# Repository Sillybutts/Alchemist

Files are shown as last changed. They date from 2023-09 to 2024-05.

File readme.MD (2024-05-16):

# Alchemist
Alchemist is the next step in the evolution of 3d printed pump action springers.

<details>
<summary>Changelog (click this text, it's a dropdown!)</summary>

- Changelog: 10-14-2023: Blaster release.
- Changelog: 3-7-2024: A bunch of updates. 
- - Updated the sear and the plunger rod to be more wear-resistant and smoother to prime. Both these parts can be installed in existing Alchemists, you just need to take off the stock and install the sear from behind the PTback. The new plunger rod and sear are marked with 'V2' on the side.
- - Updated the PTback and Skeggox PTback to have space to install the new style of sear from the front without stock disassembly in the future. 
- - Updated the Skeggox PTback to have more space for the head of the large top bolt, and more space for the screwdriver. 
- - Removed the optional secondary trigger spring. The slight benefit in trigger feel is not worth the catch issues it causes for some people. 
- - Thinned the walls on the built in supports for the picatinny rails. Used to be 1mm wide, now 0.5mm wide.
- - Tightened the picatinny keepers for the pump grip and the Skeggox stock (upon recommendation from OOD).
- - Lengthened the Skeggox picatinny rail a HAIR to fix a tolerance (upon recommendation from OOD).
- - Added two pins to the back of the Skeggox picatinny to reinforce it. The pins go into new holes in the Skeggox PTback. 
- - Extended the sear spring a little bit more via a new optional grip print.
- - Chamfered the front bottom edges of the grip panels to better clear the mag release. (same for the Lynx-grip version's grip panels). 
- - Tightened the ball detent hole by a hair. 
- - Tweaked the MagwellBack to have more mag release clearance.
- - Added a TOP marking to the top of the trigger.
- - Extended the part of the trigger that touches the sear by a little bit to remove some slop.

</details>

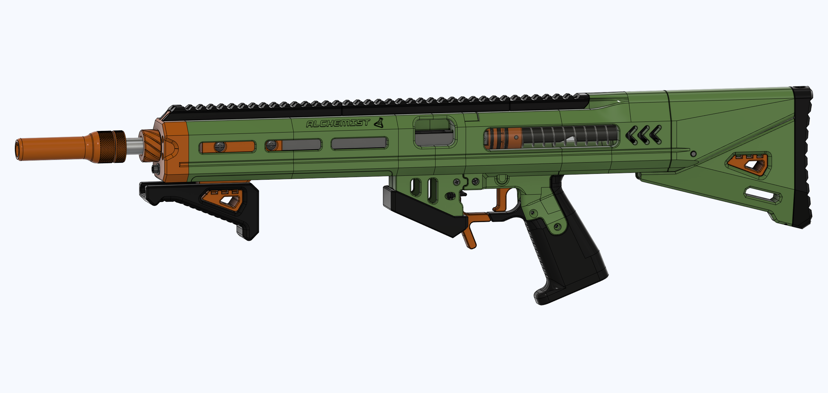
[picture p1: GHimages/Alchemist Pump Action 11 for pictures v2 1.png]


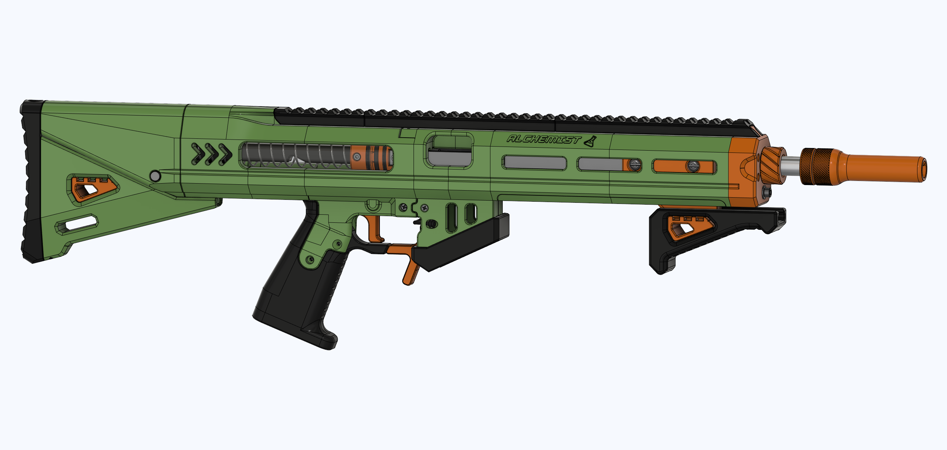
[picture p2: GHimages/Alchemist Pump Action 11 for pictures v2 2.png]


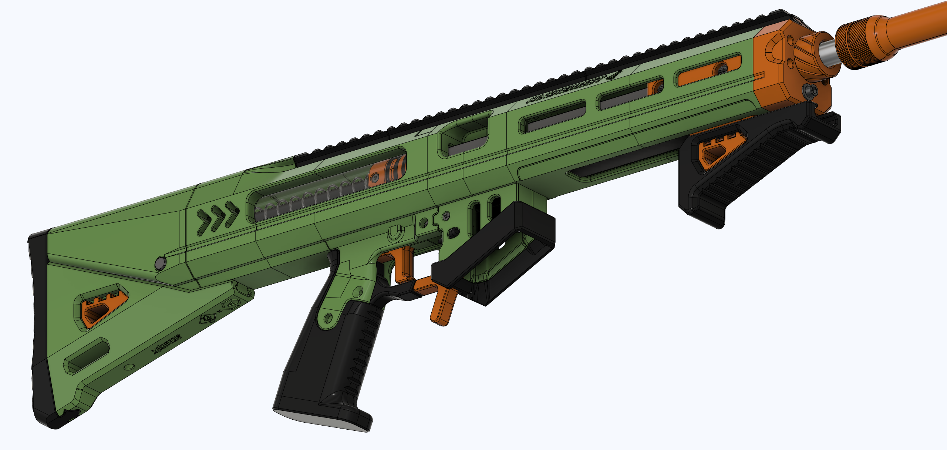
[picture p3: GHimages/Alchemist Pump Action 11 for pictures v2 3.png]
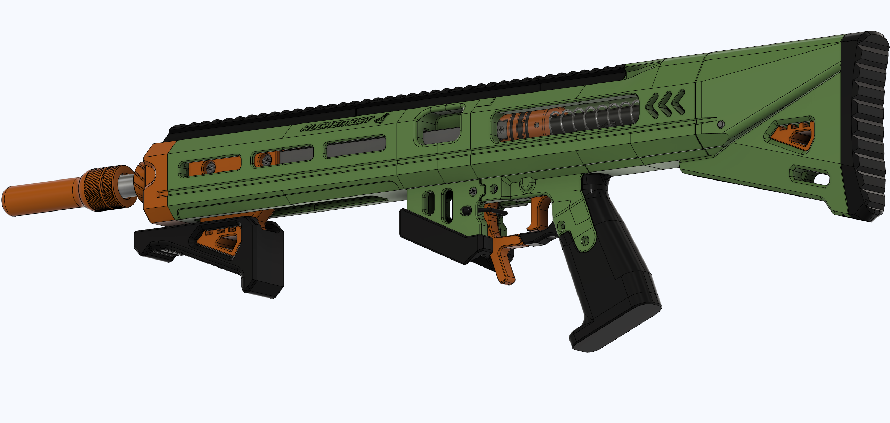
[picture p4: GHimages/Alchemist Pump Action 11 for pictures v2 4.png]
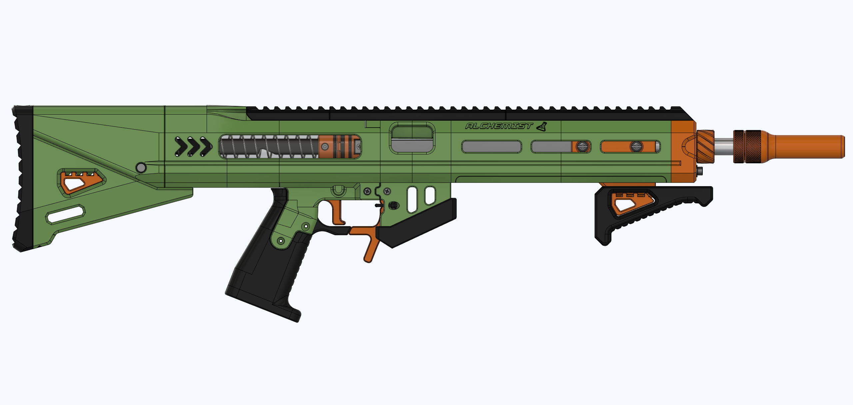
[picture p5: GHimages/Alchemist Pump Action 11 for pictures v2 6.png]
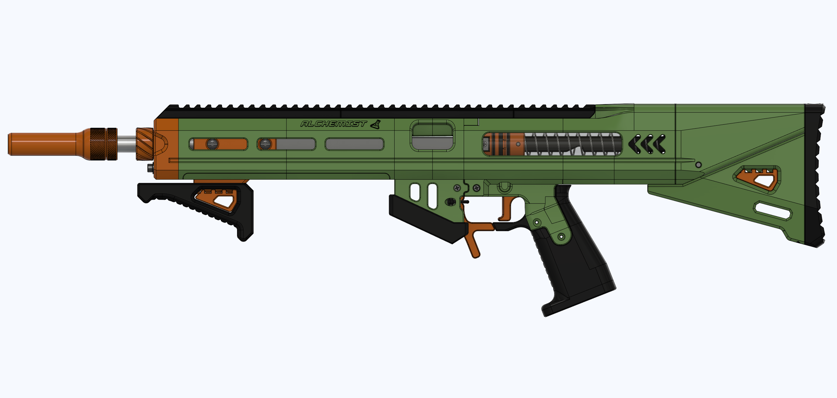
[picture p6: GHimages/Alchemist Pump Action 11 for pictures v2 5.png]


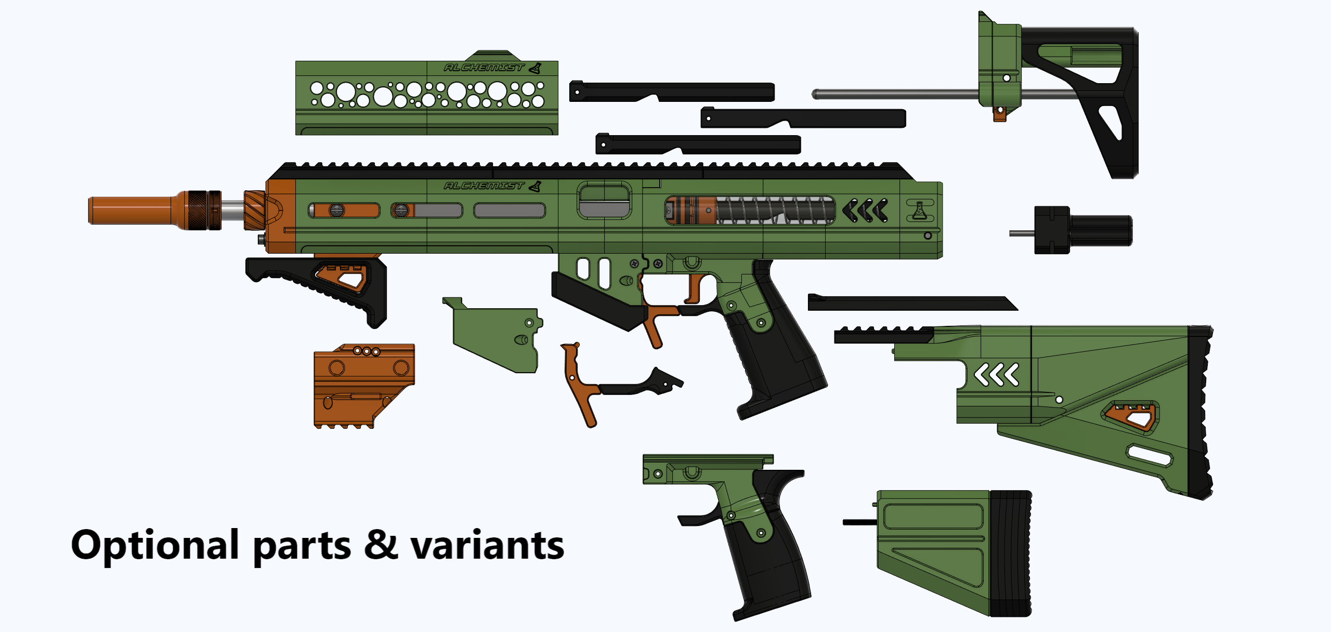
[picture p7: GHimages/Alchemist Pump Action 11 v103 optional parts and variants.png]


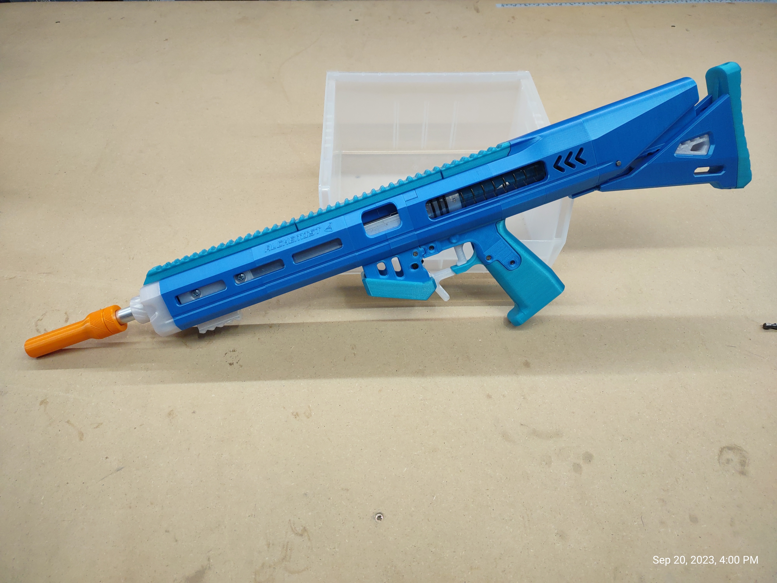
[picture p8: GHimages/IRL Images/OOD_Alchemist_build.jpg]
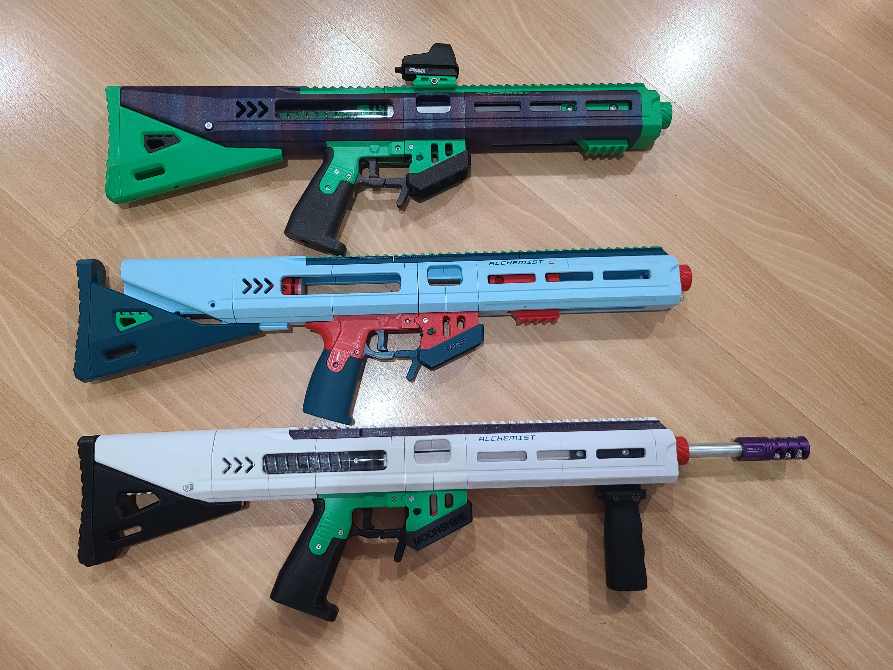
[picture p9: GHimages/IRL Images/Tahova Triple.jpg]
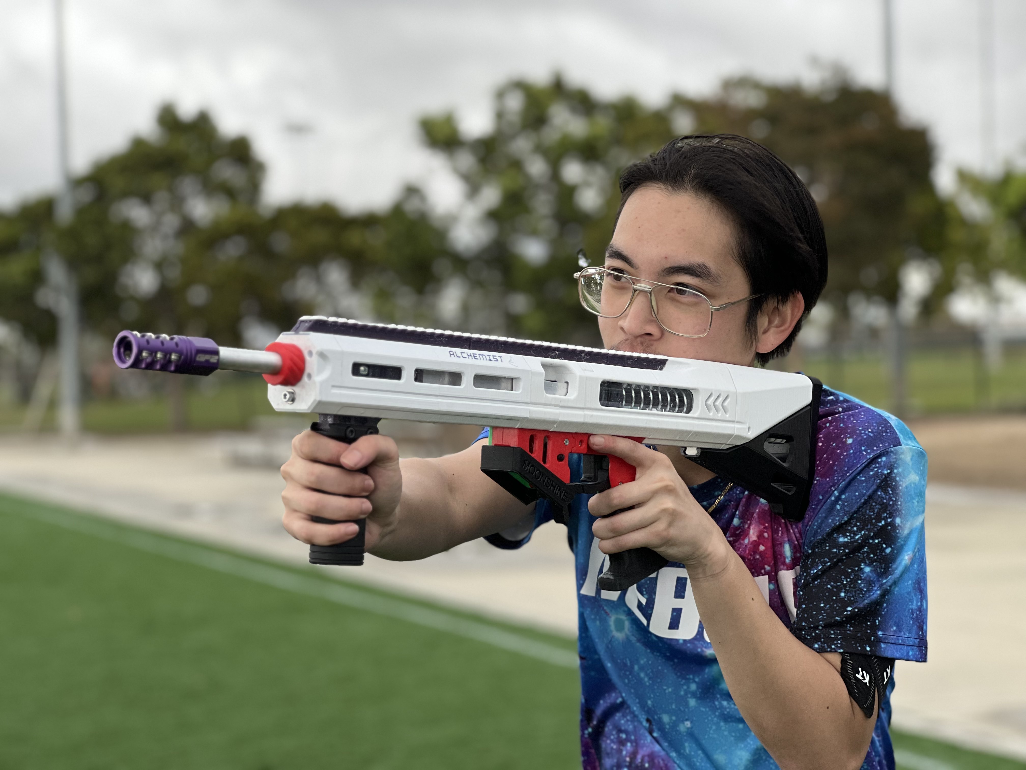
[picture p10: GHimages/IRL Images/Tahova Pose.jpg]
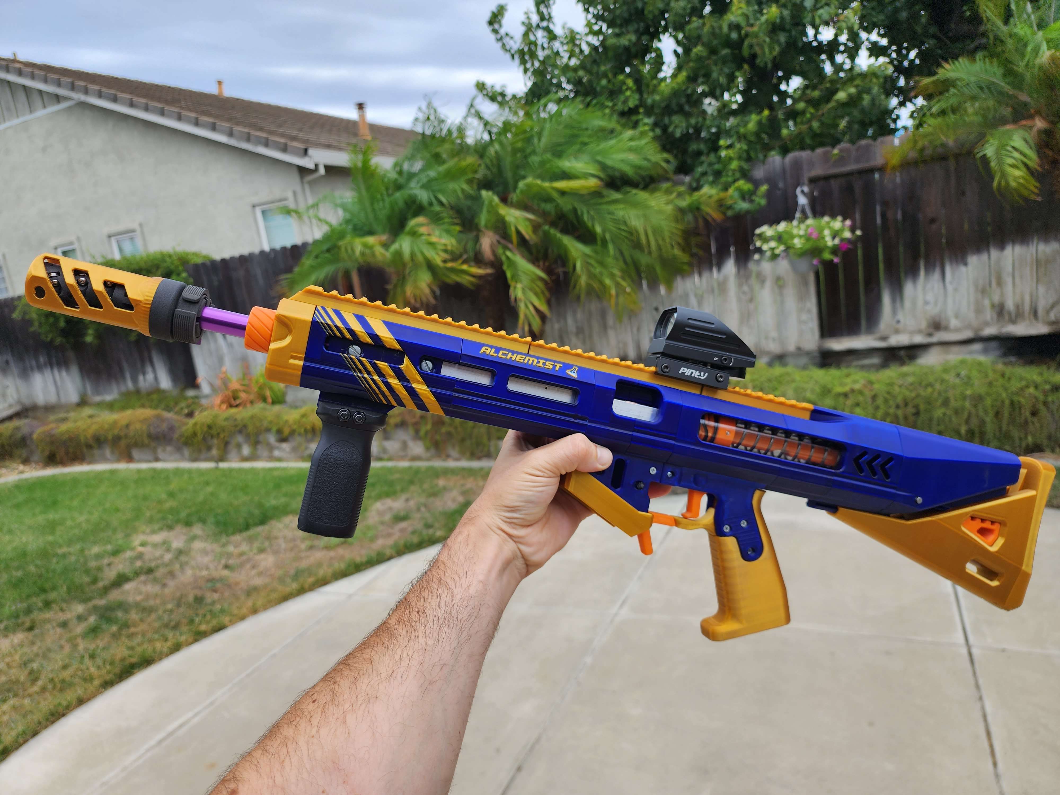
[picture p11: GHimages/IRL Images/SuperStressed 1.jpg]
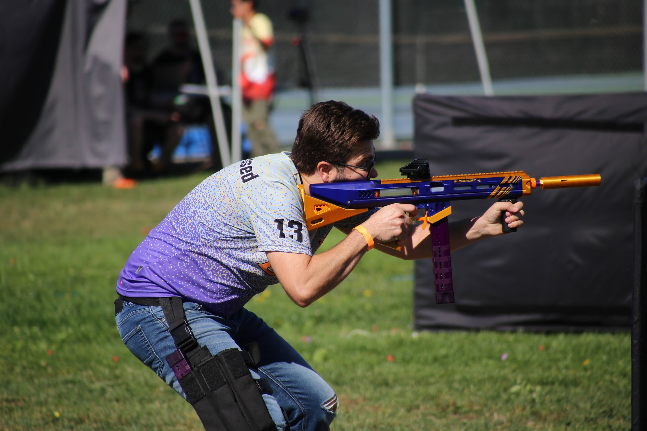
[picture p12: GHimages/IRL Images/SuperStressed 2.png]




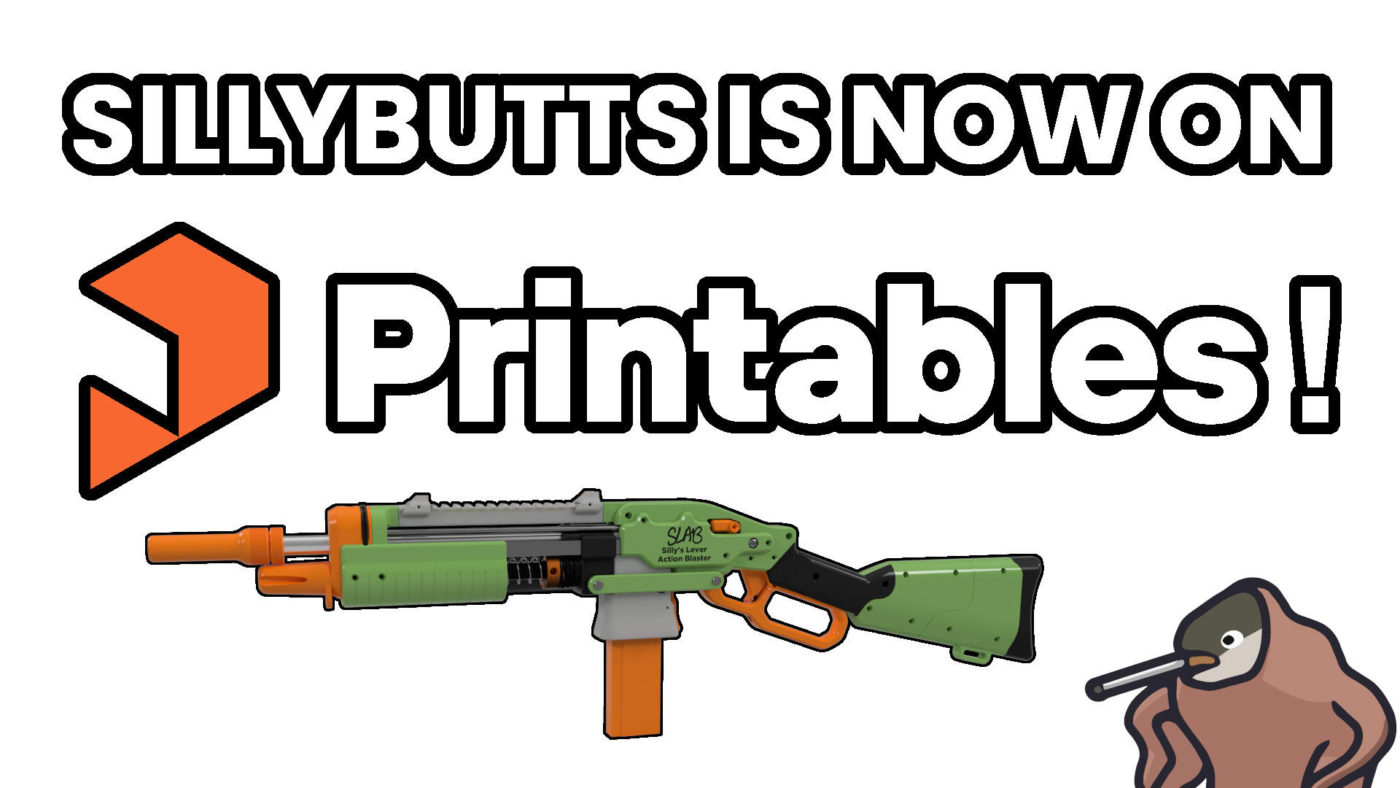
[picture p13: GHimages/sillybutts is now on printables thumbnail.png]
Printables Button


## I ALSO UPLOAD TO PRINTABLES https://www.printables.com/model/822837-alchemist-pump-action-blaster-nerf-homemade

## Description
Alchemist is the next step in the evolution of 3d printed pump action springers. Alchemist is built like a tank, has a butter smooth priming and firing feel, and is heavily customizable with alternative parts and upgrades. 

Firing Demo & Blaster Overview: https://www.youtube.com/watch?v=2bPMUlzL2F4

Pre-Release Compilation: https://youtu.be/aXrQAO-OECE

Assembly Video: https://youtu.be/UOdZIeP3myw

## "Why would I build this instead of XYZ?"

* It uses ball bearings on the priming grip, and the prime is VERY smooth.
* There is an (optional) ball detent that locks the priming grip in the forward position, so it doesn't flop around while running. Flopping is an issue experienced by most pump action springers (Talon Claw, SBL, Lynx, etc etc).
* One pin and one allen key screw to access the spring, plunger, and ram.
* The blaster is built on aluminum bars, like a Lynx. Very sturdy.
   * It also has a bar tensioner, which squeezes all the parts together like a Caliburnoid. Best of both worlds.
* Hair trigger, very quick and snappy.
* The barrel can be removed and replaced in 10 seconds, toolless.
   * If you don't care about doing barrel swaps fast, there's also an optional set screw that goes directly into the barrel, for a more permanent attachment.
* Very smooth magwell with plenty of flare for quick reloading.
* Several different stock options:
   * Compatible with the SBL/Worker adjustable stock.
   * Skeggox stock (adapted from Vikinger) - this is what is pictured in the post.
   * N-Strike lug.
   * Fixed, non adjustable printed stock, with different buttplate length options
   * Or no stock, if you don't want one lol.
* A bunch of different aesthetic and ergonomic options for the shroud, grip, plunger tube area, and magwell.
* A SLAB style plunger fits wider Lynx springs, *and* all TC springs. Lots of options.
* The blaster has a 95mm prime, which is slightly shorter than a SBL, and a good bit shorter than a TC. That allows faster priming.
* Built in spring guide as the plunger rod.
* It uses a Skewer plunger tube, so it can use metal Skewer plunger tube upgrades.
* It also uses TC ramrods, so you can use fancy anodized ones.
* The rambase is improved over a TC rambase; it has more screws to grab onto the ram.
* Very easy printing, with minimal supports.
* The picatinny rail on top has a big iron sight gutter down the middle, so you can easily aim even without any picatinny irons or a proper sight.

And more I can't remember at the time of writing. Its a good blaster, build one.



## I don't charge for my files, please consider supporting me! 

**If you enjoy the stuff I make, please consider donating via Patreon or BuyMeACoffee. Filament and prototyping stuff costs a lot! By donating, I can make more cool stuff for everyone to enjoy. Thanks!**

<a href="https://www.patreon.com/sillybutts/">Patreon Button</a> 
https://www.patreon.com/sillybutts Monthly donations

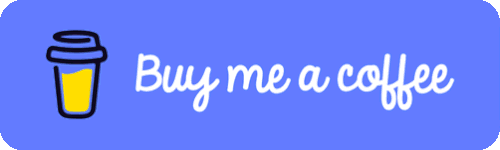
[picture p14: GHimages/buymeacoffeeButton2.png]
BuyMeACoffee Button
 
https://www.buymeacoffee.com/sillybutts One-time donations

## Reviews

Videos:
- Bradley Phillips: https://www.youtube.com/watch?v=nSymhz6XNWQ
- DrFlux: https://www.youtube.com/watch?v=KqOwWXTx2OE
- OutOfDarts: https://www.youtube.com/watch?v=WnXajnx6g8U
- SuperStressed: https://www.youtube.com/watch?v=OPx1uPWO52A

## User Images

Here's some awesome builds of Alchemist!

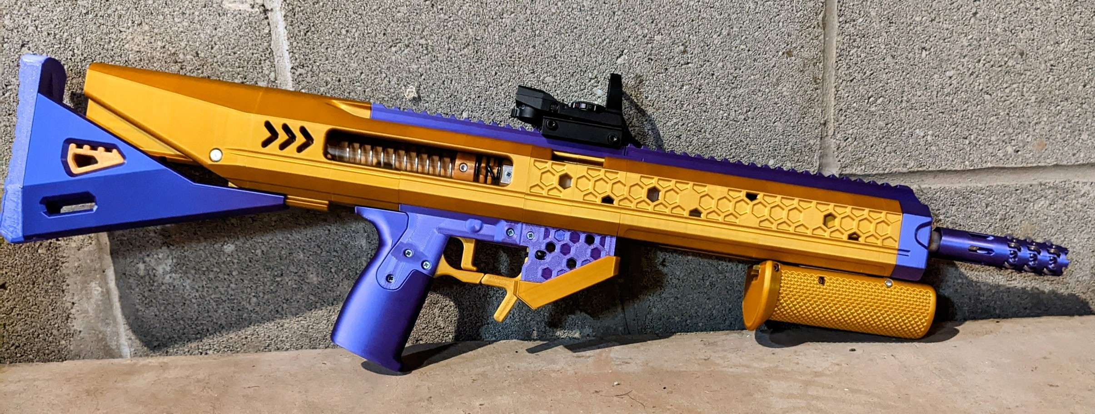
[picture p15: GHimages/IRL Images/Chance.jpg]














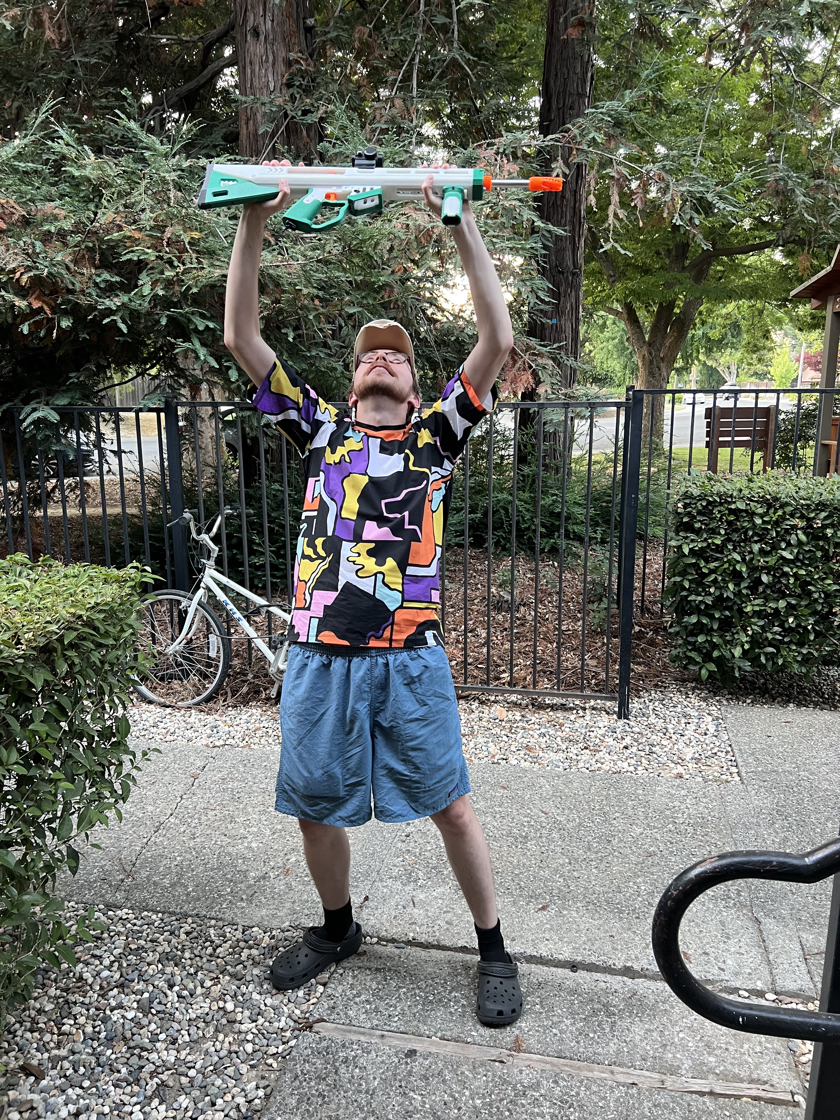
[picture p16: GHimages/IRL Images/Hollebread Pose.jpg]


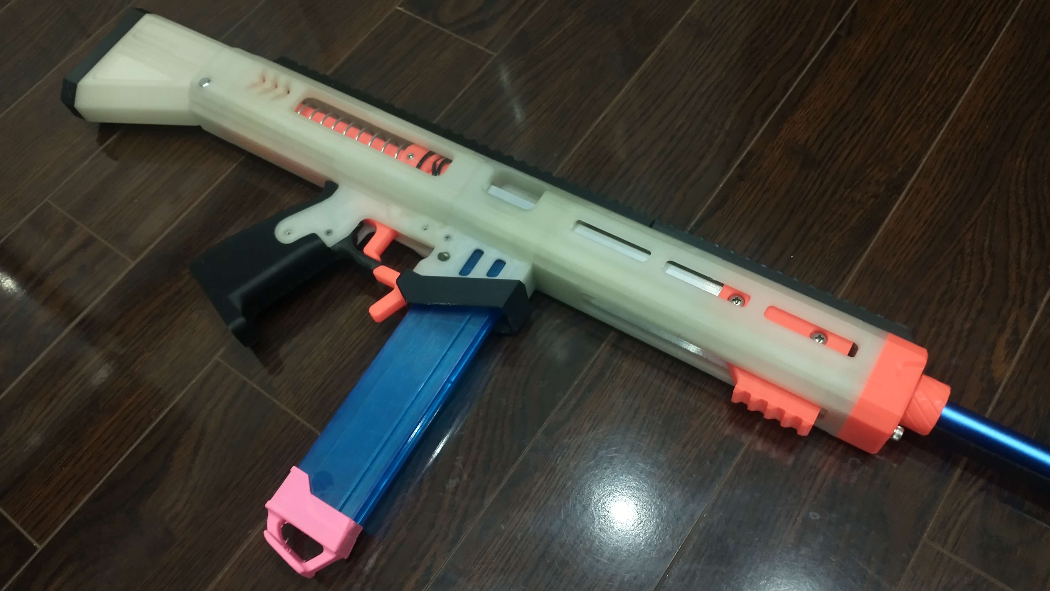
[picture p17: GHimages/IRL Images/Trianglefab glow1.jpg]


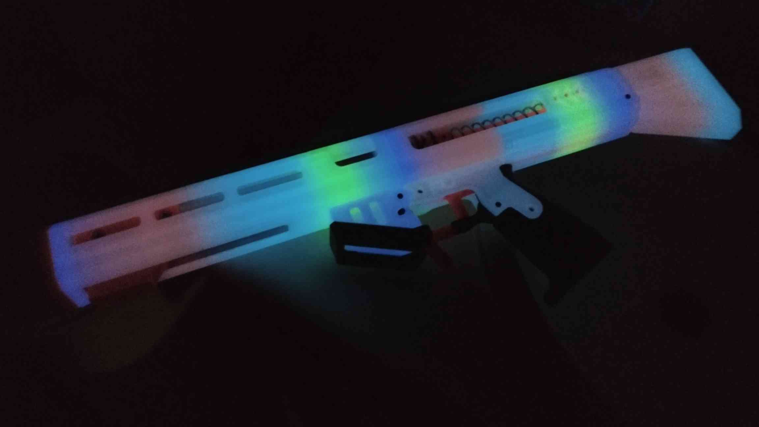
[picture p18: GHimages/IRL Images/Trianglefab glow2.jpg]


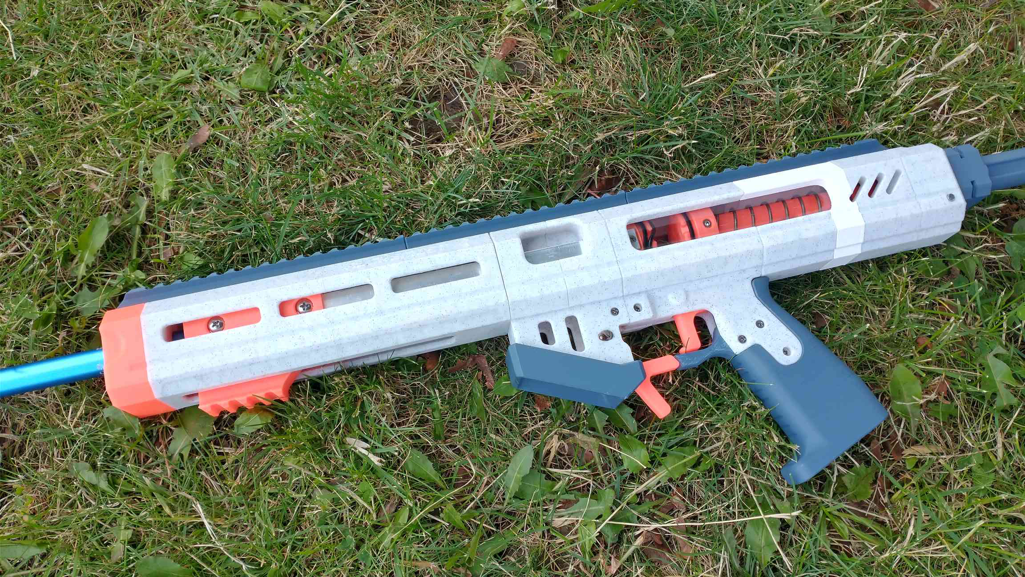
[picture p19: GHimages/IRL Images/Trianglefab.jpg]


## Optional Parts

There are a bunch of variant parts for Alchemist:
- Front Ends:
- - Standard ported front shroud, or "swiss cheesed" front shroud.
- Four grip styles:
- - Standard grip, with and without the bottom "shoe" portion.
- - Lynx-derived grip, with and without the bottom "shoe" portion.
- Four stock styles:
- - Skeggox adjustable stock, originally designed by Vikinger, and ported to Alchemist by Chance.
- - Worker/SBL1.0 Adjustable stock (thanks GavinFuzzy for help with this part).
- - Fixed non-adjustable stock with buttpads of varying height.
- - N-Strike Stock Lug.
- Optional front grip.
- Magwell panels with or without viewing slots.
- etc



Here are some good Picatinny sights if you want some:
- https://www.thingiverse.com/thing:2376150/files FrontPip and Pip in the Caliburn fileset are great iron sights.
- https://www.thingiverse.com/thing:1667830
- https://www.thingiverse.com/thing:2829229
- https://www.thingiverse.com/thing:5103083

### Performance:
As testing is done, I will update this part of the page with common spring/barrel combos for specific FPS numbers.

Keep in mind that SCARs usually reduce performance a bit.

Broadly speaking, expect a reliable and consistent FPS range of 120fps to 260fps, depending on spring and barrel combo. 

Alchemist is compatible with Talon Claw length springs, as well as larger Lynx and Nerf Longshot springs.

Expect Alchemist to hit ~20 FPS lower than a TC with an equivalent barrel and spring. Alchemist traded a shorter prime length for a smoother prime, which means there's less air volume to work with.

## Sellers

Hardware is available from these sellers:
- OutOfDarts: https://outofdarts.com/products/alchemist-hardware-kit
- - OOD aluminum bar sets: https://outofdarts.com/products/sillybutts-replacement-bolt-arms

- SilverFoxIndustries: https://silverfoxindustries.shop/products/alchemist-hardware-kit

Fully printed/assembled blasters are available from these sellers:
- OutOfDarts: https://outofdarts.com/products/alchemist-fully-assembled-blaster
- SilverFoxIndustries: https://silverfoxindustries.shop/collections/designs-by-sillybutts/products/the-alchemist-by-sillybutts

## Print Info

All STLs are exported in their correct print orientations.

Black
- 100% infill, 5 walls: MagwellChin, PlungerRod, NStrikeLug.
- 10% infill, 5 walls: FixedStock_Buttplate, TriggerGuard.
- Everything else 20% infill, 5 walls
- Supports needed for MagwellChin and NStrikeLug. RailA/B/C has built in supports, no slicer supports required.
- MagwellChin MUST BE PRINTED WITH A BRIM AND SUPPORTS, and with the long bottom area facing the print bed. 

Green
- 100% infill, 5 walls: EndCap
- 10% infill, 5 walls: FixedStock_Stock.
- Everything else 20% infill, 5 walls
- Supports needed for BarrelShroudFront, BarrelShroudBack, and PTfront.
- EndCap is intended to print with the back facing the print bed, but it can be printed with the opposite face on the print bed if you enable supports.

Orange
- 20% infill, 5 walls: FrontGripKeeper, MagRelease, MuzzleNut, Trigger, PrimingBlock.
- Everything else 100% (full) infill, 5 walls
- No supports.
- Muzzle needs to be printed with the front facing the print bed.
- BarTensioner needs to be printed with the nut-cavity facing up.
- Brims are very helpful for printing all these orange parts.
- PrimingBlock has some overhangs, but nothing too awful. DO NOT USE SUPPORTS ON IT.

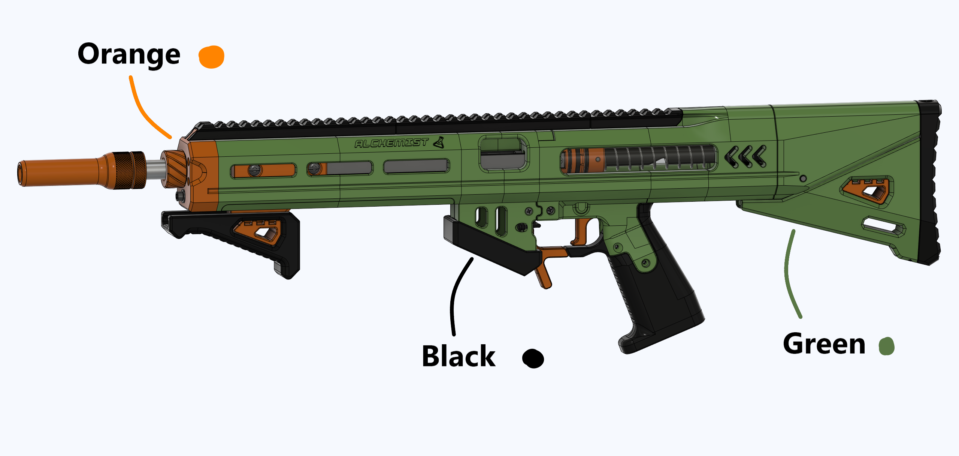
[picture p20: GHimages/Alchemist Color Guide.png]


## Hardware

Full hardware list: https://docs.google.com/spreadsheets/d/1YDkzYdij77of0HTidGjQzjRrs53viwXQVmcyhZj8VQ8/edit?usp=sharing
Make sure you have the "RELEASE VERSION" tab selected at the bottom of the page.

The "Body Aluminum Bars" are custom for this blaster. Here is a diagram of the bars if you plan to make your own. 
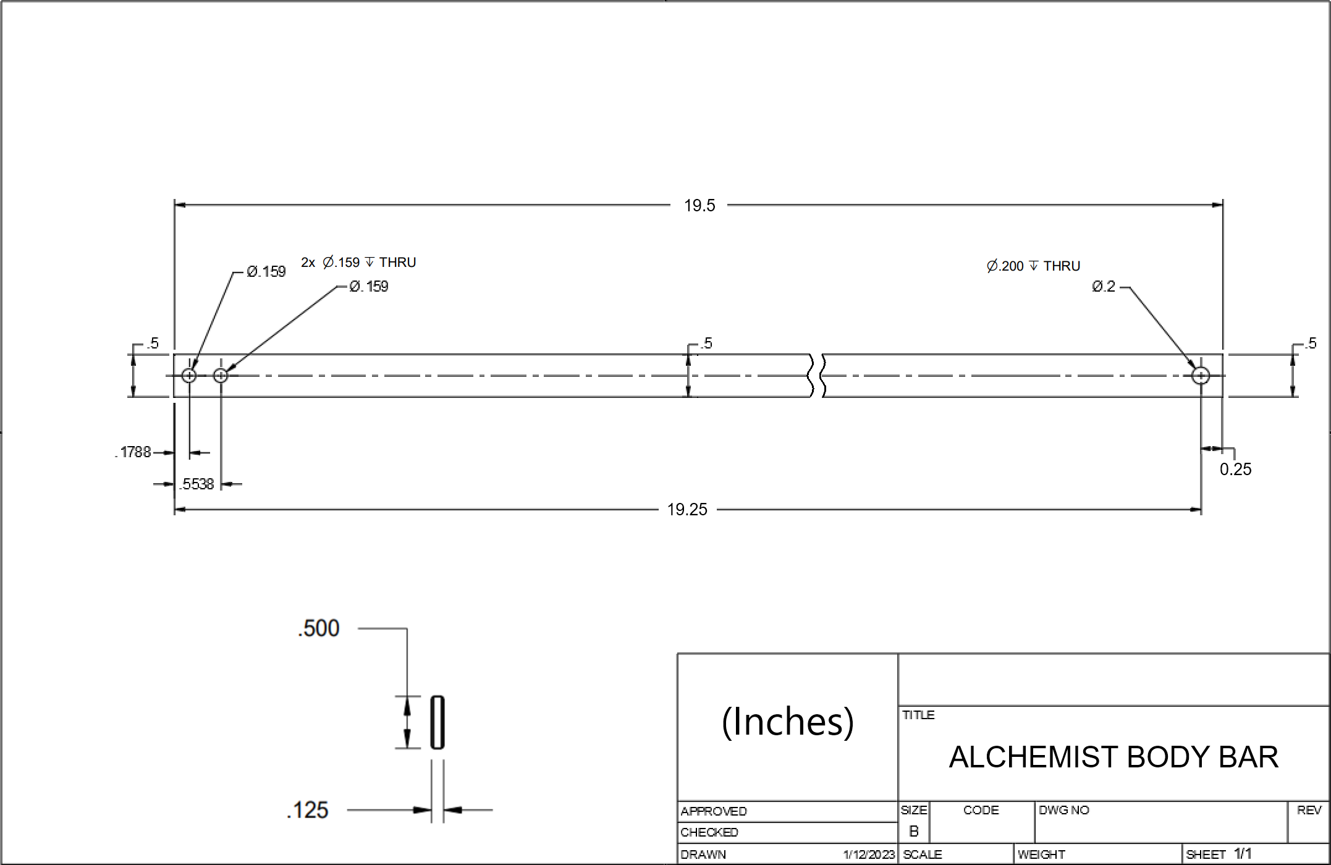
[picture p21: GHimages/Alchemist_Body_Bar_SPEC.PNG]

There is a printable cutting/drilling jig in the Tools folder of the Alchemist fileset. 

Pre-made bars can also be bought directly from:

- SilverFoxIndustries: https://silverfoxindustries.shop/products/individual-flatbar-replacement?variant=42696345714874

- OutOfDarts: https://outofdarts.com/products/sillybutts-replacement-bolt-arms?variant=40599008739370

## Assembly

Video: https://youtu.be/UOdZIeP3myw?si=pLHplAR6F4LWGuP2
Written: https://outofdarts.com/blogs/news/sillybutts-alchemist-build-guide

OOD Assembly Video: https://www.youtube.com/watch?v=4wVVx7PlVZM

Full hardware list: https://docs.google.com/spreadsheets/d/1YDkzYdij77of0HTidGjQzjRrs53viwXQVmcyhZj8VQ8/edit?usp=sharing
Make sure you have the "RELEASE VERSION" tab selected at the bottom of the page.

## Project Contributors
<details>
<summary>Thanks to the people who contributed to Alchemist! Here's a list of who did what (in no particular order): (click this text)</summary>

Beta:
- SuperStressed: Beta testing.
- Chance: Emotional support (Chance — 06/11/2023 8:16 PM: "succa my nut", 07/07/2023 5:48 PM: "lofts can suck my whole ass"). Adapted Vikinger's Skeggox stock to fit Alchemist. Did a bunch of work optimizing the positioning of the primingblock bearings.
- zoomed_out_tahova: Beta testing.
- Wonderboy: Misc help.
- Hollebread: Beta testing.
- RedCowl: Misc help.
- Meaker VI: Did some fun stuff with the initial prototype. None of it made it back into the main design, but it's still pretty neat.
- TriangleFabrications: Misc help.
- Ian Whitehouse: Misc help.
- OOD Greg: Testing help and sourcing help.
- Hotkoin: Aesthetic assistance. 

</details>

## Misc.

**If you build any of my designs, I'd love to see yours! Feel free to message me on Discord (Sillybutts#5905) or tag me on a post on Reddit (u/SillyTheGamer).**

**If you are having issues with any of my designs, please let me know.**

**If you wish to print and sell this item, please contact me for licensing. I can be reached via email at "iamsillybutts@gmail.com".**

**你好！ 我擁有這個設計。 想生產請聯繫我. 你好！ 我拥有这个设计。 如果你想生产，请联系我.**

<br />This work is licensed under a <a rel="license" href="http://creativecommons.org/licenses/by-nc-sa/4.0/">Creative Commons Attribution-NonCommercial-ShareAlike 4.0 International License</a>.

**Disclaimer: This is not a toy. This blaster is meant for hobbyists, not children. Blaster must be operated correctly to avoid injury. I am not responsible for any injuries from this blaster. Please use a bright/blaze orange muzzle and barrel cap on this blaster. Consult local laws before building this high powered blaster.**

## If you like what I do, please consider supporting me!

**I don't charge for my files, so any donations or merch purchases would be greatly appreciated!**

<a href="https://www.patreon.com/sillybutts/">Patreon Button</a> 
https://www.patreon.com/sillybutts Monthly donations

<a href="https://www.buymeacoffee.com/sillybutts/">BuyMeACoffee Button</a> 
https://www.buymeacoffee.com/sillybutts One-time donations

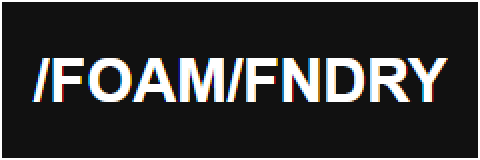
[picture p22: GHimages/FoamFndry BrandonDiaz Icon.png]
FoamFNDRY Button
 
https://brandondiaz.me/product/foam-fndry-sillybutts AWESOME shirts made in collab with Brandon Diaz! 

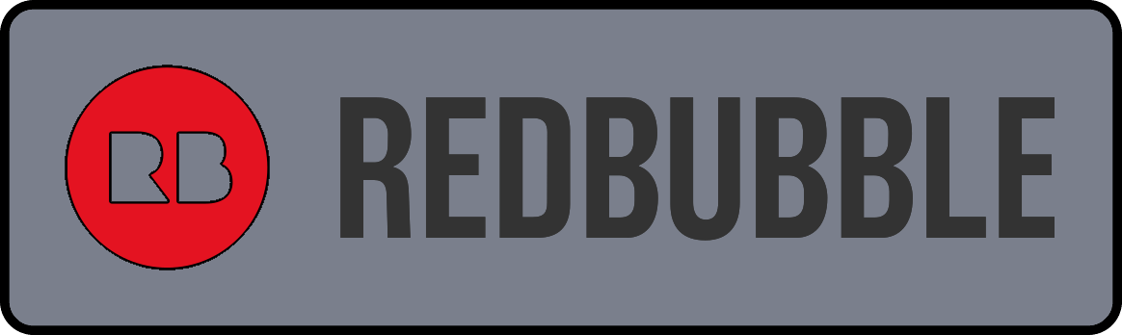
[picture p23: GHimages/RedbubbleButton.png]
RedBubble Button
 
https://www.redbubble.com/people/Sillybutts/shop RedBubble full of fun Nerf-y sticker and merch designs!  

## Images















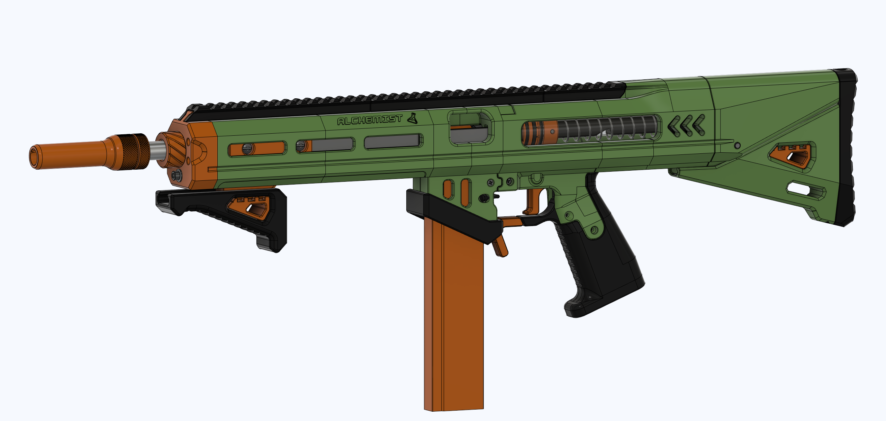
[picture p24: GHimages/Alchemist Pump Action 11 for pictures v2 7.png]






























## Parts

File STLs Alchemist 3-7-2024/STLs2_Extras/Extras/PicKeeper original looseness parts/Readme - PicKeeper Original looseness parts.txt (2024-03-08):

These parts are pre-3/7/2024 update. They have the original "looser" sizing of the Picatinny Keeper and surrounding parts.

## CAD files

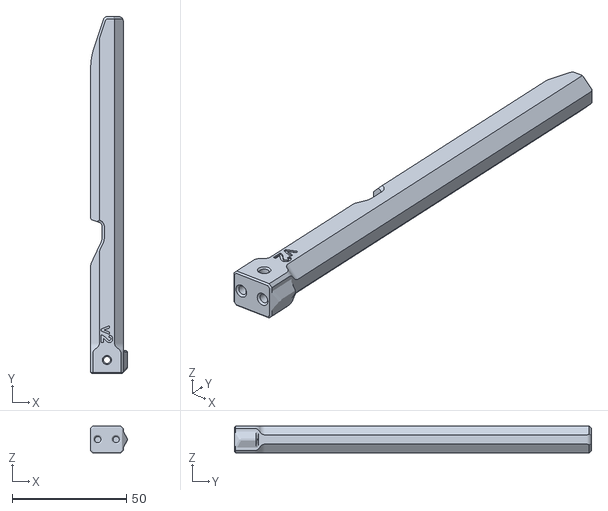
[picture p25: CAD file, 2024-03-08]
STLs Alchemist 3-7-2024/STLs1_Main/Black/Alternate plunger rods/PlungerRod_ThinnerForK26 March2024Update.stl
16.1 x 156.2 x 11.7

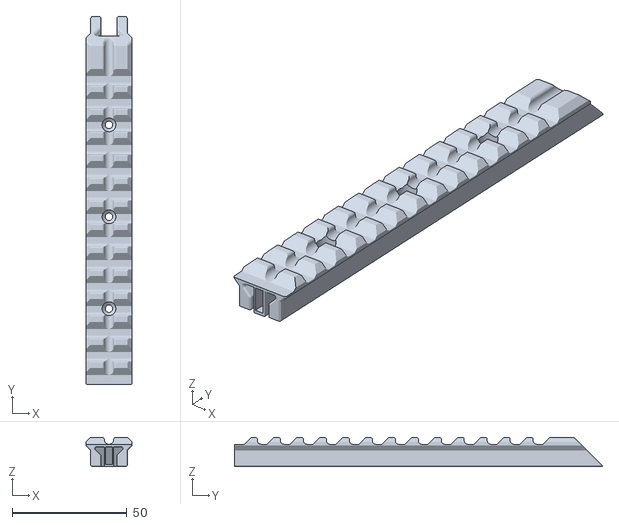
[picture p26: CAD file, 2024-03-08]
STLs Alchemist 3-7-2024/STLs1_Main/Black/Rail_C.stl
20.2 x 160.2 x 12.7

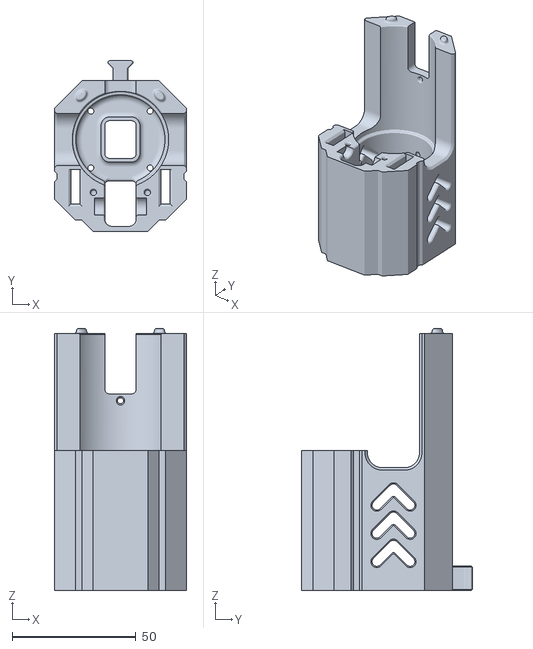
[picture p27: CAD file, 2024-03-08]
STLs Alchemist 3-7-2024/STLs1_Main/Green/PTback.stl
53.6 x 69.1 x 106.1

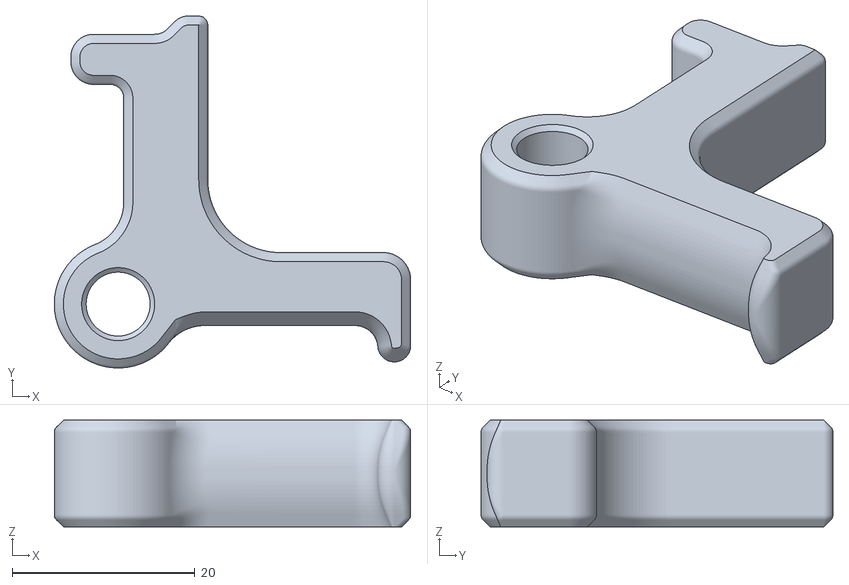
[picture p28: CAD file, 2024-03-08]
STLs Alchemist 3-7-2024/STLs1_Main/Orange/Trigger.stl
39.1 x 38.6 x 11.7

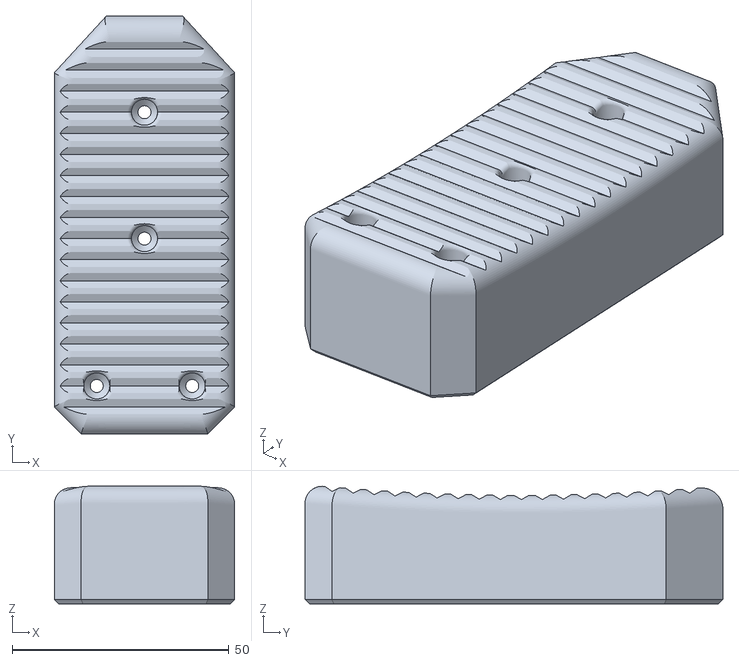
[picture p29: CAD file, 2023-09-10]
STLs Alchemist 3-7-2024/STLs1_Main/Stocks/Fixed Stock/FixedStock_Buttplate_25mm.stl
41.6 x 96.4 x 27.1

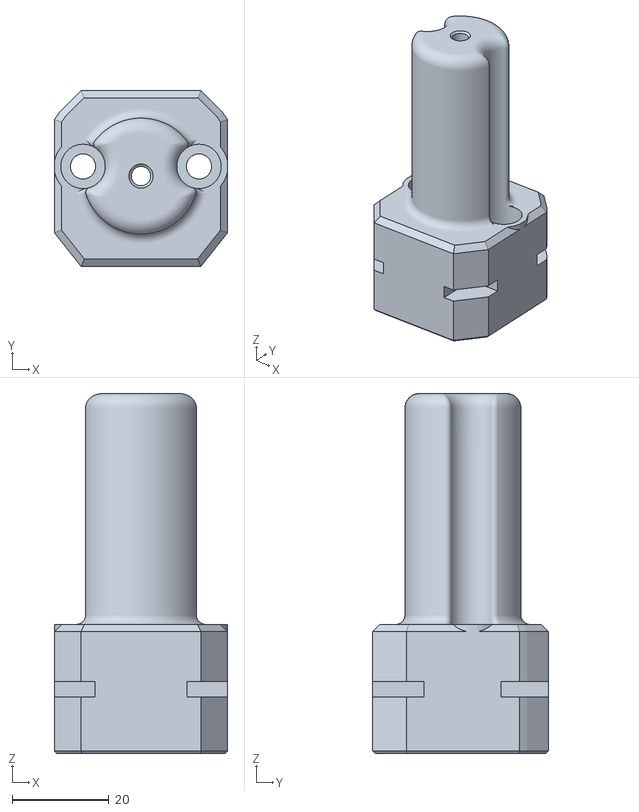
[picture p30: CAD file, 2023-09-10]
STLs Alchemist 3-7-2024/STLs1_Main/Stocks/N-Strike Stock Lug/NStrikeLug.stl
35.9 x 36.4 x 74.5

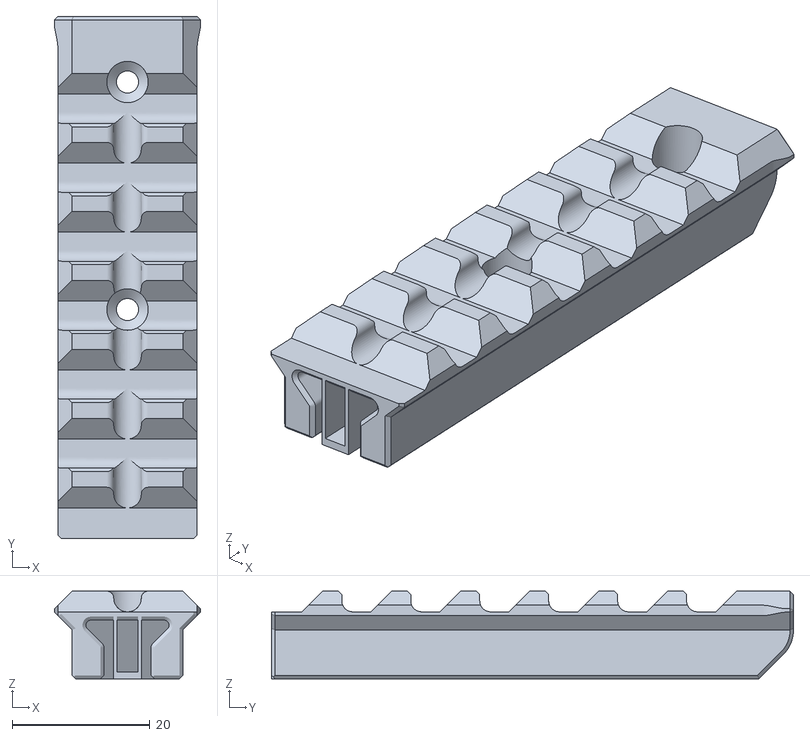
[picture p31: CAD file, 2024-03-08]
STLs Alchemist 3-7-2024/STLs1_Main/Stocks/Skeggox Stock/Skeggox_Rail_C.stl
21.2 x 75.7 x 12.7

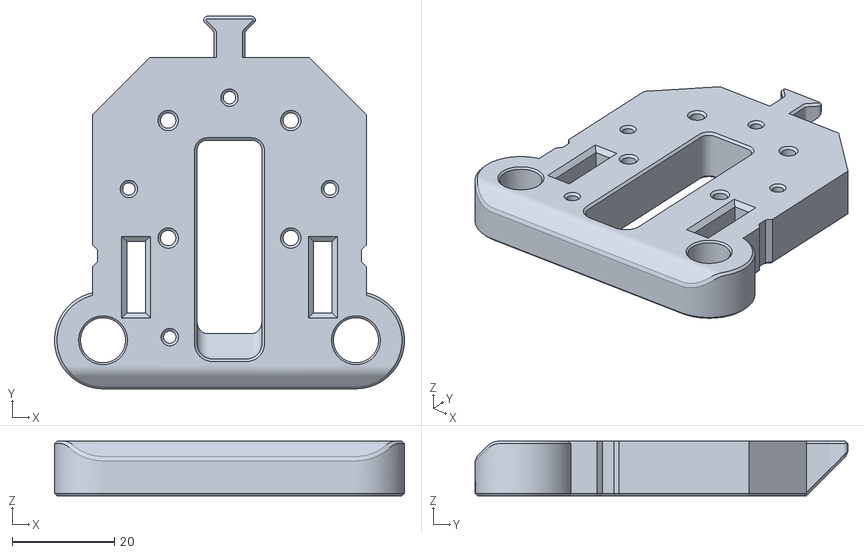
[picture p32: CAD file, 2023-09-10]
STLs Alchemist 3-7-2024/STLs1_Main/Stocks/Worker-SBL Stock/SBLWRKRSTOCK_EndCapA.stl
68.5 x 72.9 x 10.7

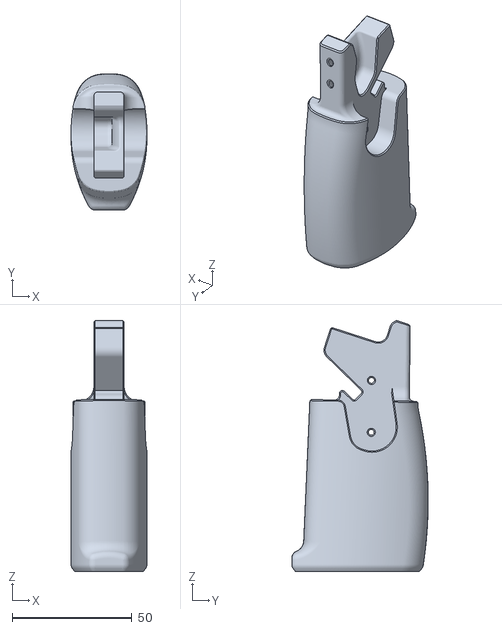
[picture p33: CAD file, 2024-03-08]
STLs Alchemist 3-7-2024/STLs2_Extras/Extras/Lynx Grip/Lynx_GripBody_NoShoe.stl
31.7 x 57.0 x 104.9

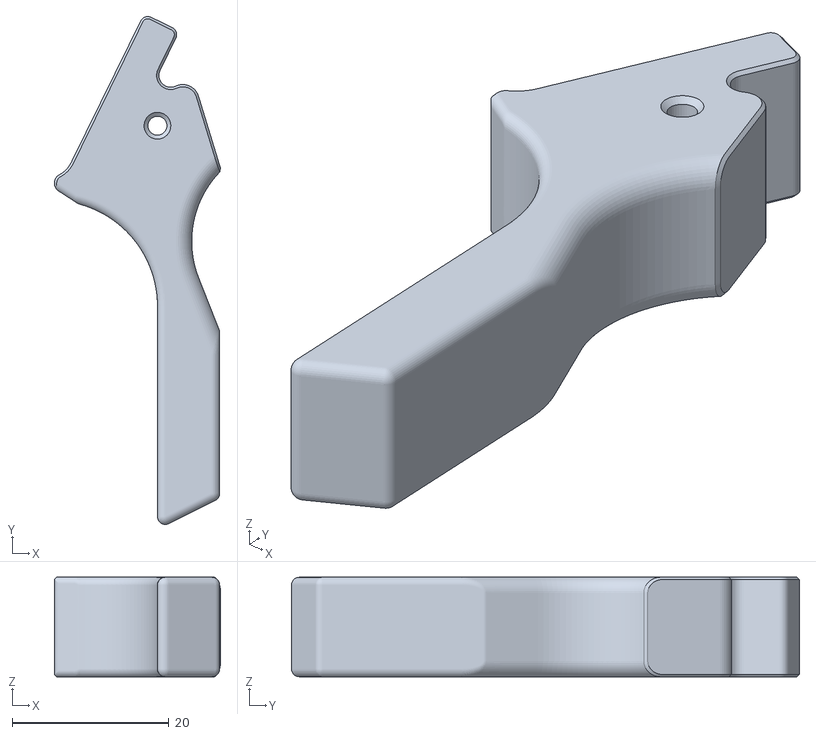
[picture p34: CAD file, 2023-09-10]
STLs Alchemist 3-7-2024/STLs2_Extras/Extras/Mag Release with more Trigger Guard space/SmallerArm_TriggerGuard.stl
21.2 x 64.8 x 12.7

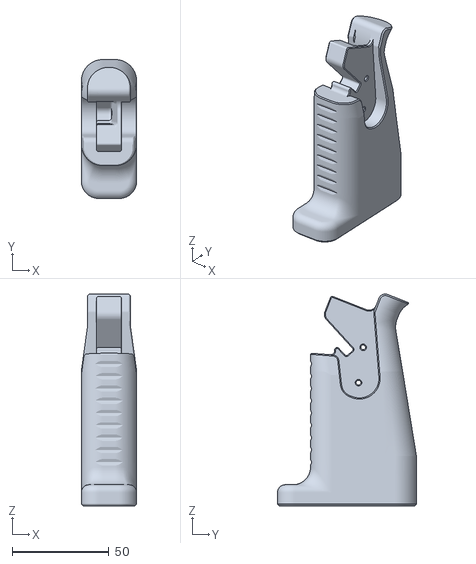
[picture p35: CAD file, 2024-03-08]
STLs Alchemist 3-7-2024/STLs2_Extras/Extras/More Sear Spring Tension via new grip/GripBody_WithShoe_MoreSpringExtension.stl
28.6 x 71.8 x 109.5

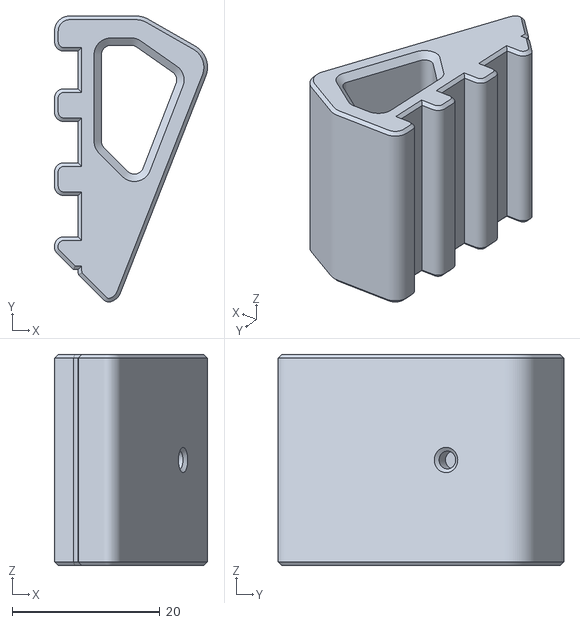
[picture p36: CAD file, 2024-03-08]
STLs Alchemist 3-7-2024/STLs2_Extras/Extras/PicKeeper original looseness parts/original FrontGripKeeper.stl
20.7 x 38.7 x 28.6

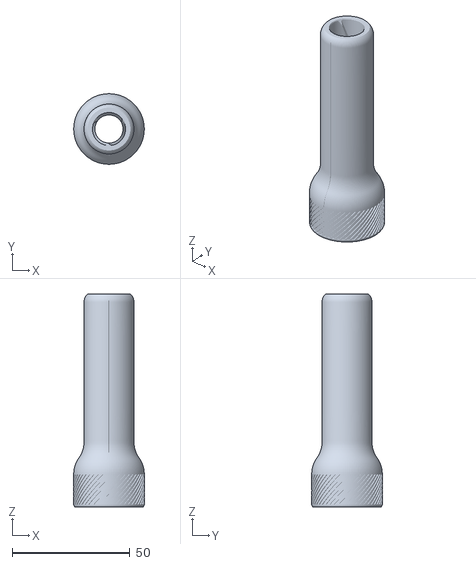
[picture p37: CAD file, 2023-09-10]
STLs Alchemist 3-7-2024/STLs2_Extras/Extras/SpigotSCAR/SpigotSCAR_Trivictus MXLspigotSCAR.stl
30.0 x 30.0 x 90.5

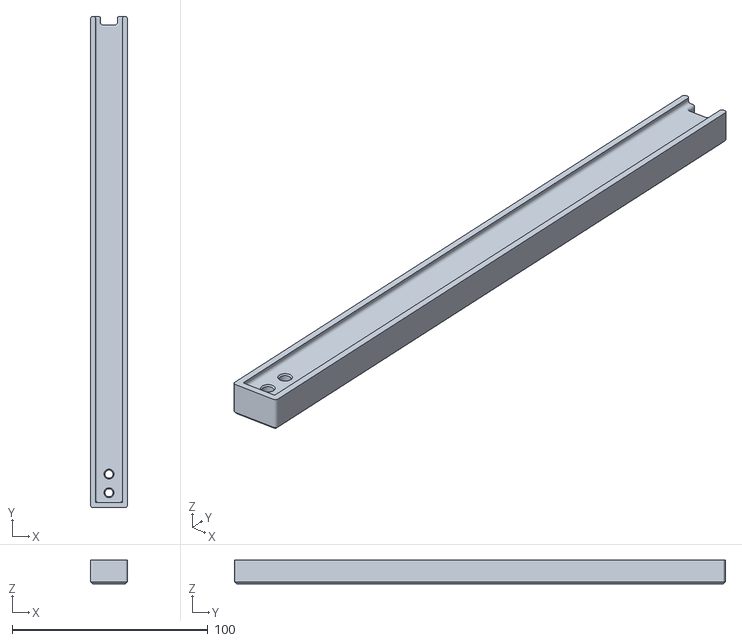
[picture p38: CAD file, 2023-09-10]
STLs Alchemist 3-7-2024/STLs2_Extras/Extras/Tools/BarDrillingJigA.stl
18.7 x 250.6 x 12.0

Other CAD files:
STLs Alchemist 3-7-2024/STLs1_Main/Black/Alternate plunger rods/PlungerRod_ThinnerForK26_TroubleshootingFix March2024Update.stl
STLs Alchemist 3-7-2024/STLs1_Main/Black/Rail_B.stl
STLs Alchemist 3-7-2024/STLs1_Main/Green/Grip_Left.stl
STLs Alchemist 3-7-2024/STLs1_Main/Orange/Sear March2024Update.stl
STLs Alchemist 3-7-2024/STLs1_Main/Black/Alternate plunger rods/PlungerRod_TroubleshootingFix March2024Update.stl
STLs Alchemist 3-7-2024/STLs1_Main/Black/FrontGrip.stl
STLs Alchemist 3-7-2024/STLs1_Main/Black/GripBody_NoShoe.stl
STLs Alchemist 3-7-2024/STLs1_Main/Black/GripBody_WithShoe.stl
STLs Alchemist 3-7-2024/STLs1_Main/Black/MagwellChin.stl
STLs Alchemist 3-7-2024/STLs1_Main/Black/PlungerRod March2024Update.stl
STLs Alchemist 3-7-2024/STLs1_Main/Black/Rail_A.stl
STLs Alchemist 3-7-2024/STLs1_Main/Black/Rail_C_Smooth.stl
STLs Alchemist 3-7-2024/STLs1_Main/Black/TriggerGuard.stl
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

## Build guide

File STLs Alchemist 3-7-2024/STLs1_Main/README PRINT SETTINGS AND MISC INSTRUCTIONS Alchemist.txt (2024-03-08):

ALCHEMIST BLASTER FILESET README.
By Sillybutts. 3/7/2024
---------------------------------------------------------------------------------------------
Hardware list and bar specs: https://docs.google.com/spreadsheets/d/1YDkzYdij77of0HTidGjQzjRrs53viwXQVmcyhZj8VQ8/edit?usp=sharing

Assembly video: https://youtu.be/UOdZIeP3myw?si=pLHplAR6F4LWGuP2
---------------------------------------------------------------------------------------------

Print settings:

All STLs are exported in their correct print orientations.

Black
- 100% infill, 5 walls: MagwellChin, PlungerRod, NStrikeLug.
- 10% infill, 5 walls: FixedStock_Buttplate, TriggerGuard.
- Everything else 20% infill, 5 walls
- Supports needed for MagwellChin and NStrikeLug. RailA/B/C has built in supports, no slicer supports required.
- MagwellChin MUST BE PRINTED WITH A BRIM AND SUPPORTS, and with the long bottom area facing the print bed. 

Green
- 100% infill, 5 walls: EndCap
- 10% infill, 5 walls: FixedStock_Stock.
- Everything else 20% infill, 5 walls
- Supports needed for BarrelShroudFront, BarrelShroudBack.
- EndCap is intended to print with the back facing the print bed, but it can be printed with the opposite face on the print bed if you enable supports.

Orange
- 20% infill, 5 walls: FrontGripKeeper, MagRelease, MuzzleNut, Trigger, PrimingBlock.
- Everything else 100% (full) infill, 5 walls
- No supports.
- Muzzle needs to be printed with the front facing the print bed.
- BarTensioner needs to be printed with the nut-cavity facing up.
- Brims are very helpful for printing all these orange parts.
- PrimingBlock has some overhangs, but nothing too awful. DO NOT USE SUPPORTS ON IT.

---------------------------------------------------------------------------------------------

Misc notes:

- WATCH THE ASSEMBLY VIDEO, IT IS VERY IMPORTANT.

- Use the "PT gauge" misc print to trim a TC plunger tube to Skewer length, or check which one you have.
- Use the "BarDrillingJig A/B" to make your own bars. Glue together the two prints at the "tooth" edge. 
- Life pro tip: put the bearings into the PrimingBlock slots with needle nose pliers, its easier to line up with the pockets.
- The PrimingBlock bearing slots have adjustability, make sure its as close to the barrel/bars as possible without having undue friction. 
- Lubing the outsides of the ball bearings can make things a little bit smoother if desired.
- The little screw to keep the barrel in place is optional, the blaster works fine using just the printed muzzle nut+o-ring.
- The barrel screw goes into a square nut. The square nut goes into the front of the FrontShroud part, and is held in by a 4-40 screw next to the nut.
- If the plunger isn't catching, make sure the bars are tensioned all the way, and that you have the rubber plunger padding installed.
- The plunger uses 2x M3x16 screws, 1x M3x30 screw.
- Slide the ram into RamBaseFront before putting on the 3x 012 o-rings (two on the tip, one around the bottom, which is then squeezed by the RamBaseBack to make an air seal).
- Make sure the ram is straight when tightening the 4 locking 4-40 screws.

---------------------------------------------------------------------------------------------

March 3/7/2024 update notes:

List of changed parts in this update:
- DetentBlock
- FrontGrip
- Grip_Left (and Lynx variant)
- Grip_Right (and Lynx variant)
- GripBody (all variants)
- MagwellBack
- PicKeeper (the part that inserts into the FrontGrip and the Skeggox stock)
- Plunger Head (A and B)
- Plunger Rod (all variants)
- PTback (and Skeggox stock version)
- All picatinny rails (A,B,C,Csmooth,Cskeggox)
- Sear
- Trigger
- Skeggox_Top
- Skeggox_Bottom

I recommend that people who already own Alchemists switch to using the new PlungerRod, Sear, and Trigger. This will improve catch reliability. 
These 3 parts can be installed in existing Alchemists, you just need to take off the stock and install the sear from behind the PTback. 
The new plunger rod and sear are marked with 'V2' on the side.

I also recommend that people remove the previously optional extra spring that went beneath the trigger. 
The spring works for some people (to make the trigger pull lighter), but the reliability issues for other people isn't worth the headache. So it is fully removed.

The FrontGrip, Skeggox_Bottom, and all the PicKeepers were tightened in this update. If your print tolerances do not allow for this change, the old looser files are in the Extras STL folder.

---------------------------------------------------------------------------------------------

Full changelog:

- Changelog: 10-14-2023: Blaster release.
- Changelog: 3-7-2024: A bunch of updates. 
- - Updated the sear and the plunger rod to be more wear-resistant and smoother to prime. Both these parts can be installed in existing Alchemists, you just need to take off the stock and install the sear from behind the PTback. The new plunger rod and sear are marked with 'V2' on the side.
- - Updated the PTback and Skeggox PTback to have space to install the new style of sear from the front without stock disassembly in the future. 
- - Updated the Skeggox PTback to have more space for the head of the large top bolt, and more space for the screwdriver. 
- - Removed the optional secondary trigger spring. The slight benefit in trigger feel is not worth the catch issues it causes for some people. 
- - Thinned the walls on the built in supports for the picatinny rails. Used to be 1mm wide, now 0.5mm wide.
- - Tightened the picatinny keepers for the pump grip and the Skeggox stock (upon recommendation from OOD).
- - Lengthened the Skeggox picatinny rail a HAIR to fix a tolerance (upon recommendation from OOD).
- - Added two pins to the back of the Skeggox picatinny to reinforce it. The pins go into new holes in the Skeggox PTback. 
- - Extended the sear spring a little bit more via a new optional grip print.
- - Chamfered the front bottom edges of the grip panels to better clear the mag release. (same for the Lynx-grip version's grip panels). 
- - Tightened the ball detent hole by a hair. 
- - Tweaked the MagwellBack to have more mag release clearance.
- - Added a TOP marking to the top of the trigger.
- - Extended the part of the trigger that touches the sear by a little bit to remove some slop.

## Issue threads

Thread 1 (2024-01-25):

I have some questions

radiotbo1, 2024-01-25:
What is the total weight of the blaster?
How many Kg of filament do you need to print it?
How many Kg of each color do you need?

Amazing blaster!!!!!

Sillybutts, 2024-02-05:
1. I haven't weighed an Alchemist yet, I'll do so this week for you.
2. Total filament of ~1305g, including supports and brims.
3. 785g for the Green parts, 275g for the Black parts, 245g for the Orange parts. This is with the Skeggox stock.

minystreem56, 2024-02-13:
Adding on to this sorta lol, should this be printed with somthing like PETG?

Sillybutts, 2024-02-17:
@radiotbo1 1. Alchemist weight: Approx 3.5 pounds when using the included SCAR and the Skeggox stock option.

@minystreem56 Everything I've released thus far is designed for PLA. PETG has shown some weird issues with bending or snapping for some of the parts on previous designs (like plunger rods or sears), so I usually _specifically_ recommend PLA or PLA+ for my designs.

minystreem56, 2024-02-17:
ok!

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

--
*Sam Lewis*
*Founder and Lead Developer*
*BetaCat*

Closed 2024-02-17.

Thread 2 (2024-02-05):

SLS printing?

minystreem56, 2024-02-05:
Would I be able to print this with a SLS printer? I love the super nice finnish and having no supports.

Sillybutts, 2024-02-05:
I have not looked into how SLS will work with stuff taking an impact. iirc, SLS tends to be more brittle? So stuff like the Sear, Plunger & PlungerRod, MagwellBack, and the BarTensioner might have issues with wear or breakage. So SLS is a "maybe?"

For Resin printing, Alchemist is pretty much a no-go. It'd be way too heavy, and resin prints would probably shatter.

minystreem56, 2024-02-05:
Thanks!

Closed 2024-02-05.

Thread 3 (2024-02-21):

Advice regarding Detent Block

CodebyADHawk, 2024-02-21:
I'm currently working on printing and building the Alchemist and I ran into an issue with fit of the detent ball into the detent block. For some reason, my printer elongated the circular hole for the detent slightly. It might have to do with print orientation and vibration - I'm not 100% sure. It seems a bit odd as other parts have printed well within tolerances. In the build video, I know you mentioned glue as an option of last resort. I was thinking of possibly trying to print the detent block at 99% scale to see if that might help. Do you see any potential issues with fitment of that part at 99%? Any other advice or pointers for this issue are also appreciated.

Sillybutts, 2024-02-21:
99% should work. I am planning an update to the fileset this month that should fix the ball detent installation and some other things about the blaster. There's going to be another 4-40 screw that gets driven into the side of the detent to keep it in place, instead of relying on friction.

Closed 2024-02-21.

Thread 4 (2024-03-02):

Skeggox_Buttplate_HORIZONTALPRINT STL file missing reinforcement bolt hole

CodebyADHawk, 2024-03-02:
Hi,

We discovered after printing the HORIZONTALPRINT version of the Skeggox buttplate that file seems to be missing the hole for the reinforcement bolt. Could you please review and update the file? The VERTICALPRINT STL seems to be correct.

Sillybutts, 2024-03-02:
The horizontal print does not need the reinforcement bolt. The vertical print has it due to the weaker print orientation. Horizontal is plenty strong enough :)

Closed 2024-03-02.

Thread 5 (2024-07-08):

Missing spring holes in grips

jengo, 2024-07-08:
I started to assemble my blaster, when I realized the spring hole in the grips is missing from the STLs.  The top grip in the image is from the files directly in the .zip file from git.  The bottom grip was printed after I exported from the "Files for designers".  Additionally, the "files for designers" doesn't appear to be updated since 2023/11/11.

Also, what is the difference between the "files for designers" plain and blank template versions ?  I can't seem to find the difference between the two.

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

jengo, 2024-07-10:
It appears that the trigger is also missing the spring slot from the STL in git, had to export it

Sillybutts, 2024-07-11:
The spring there has been removed in the most recent versions of Alchemist.

It's only purpose was to make the trigger lighter.

However, it appears that many people have poorly tuned printers, to the point where the tolerances make this extra spring trip the sear prematurely.

Ie, for some people, this spring makes the blaster not work correctly.

So, since it was only an optional piece, I've fully removed it for everyone to prevent issues.

Closed 2024-07-11.
